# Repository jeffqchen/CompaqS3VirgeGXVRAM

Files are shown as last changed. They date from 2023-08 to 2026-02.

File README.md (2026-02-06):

# VRAM Expansion Board for Compaq S3 Virge GX & Matrox Mystique 220 Video Cards

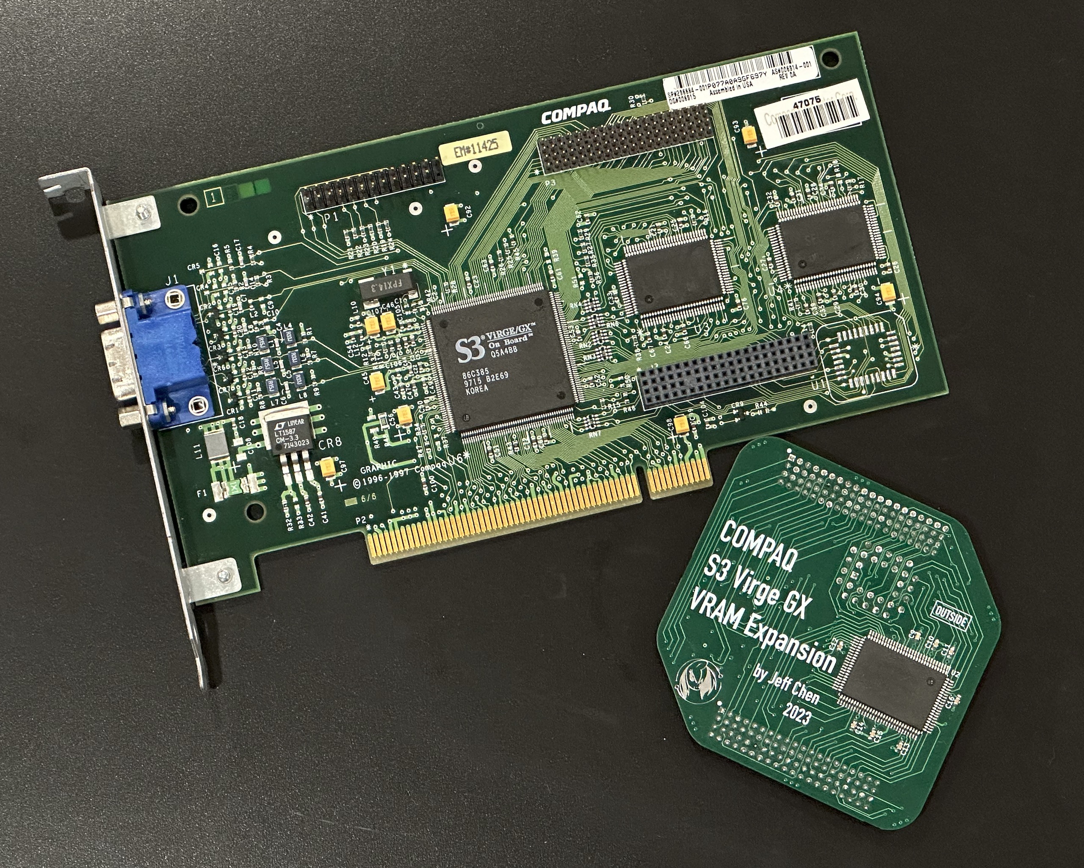
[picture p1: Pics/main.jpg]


The Compaq S3 Virge GX video card comes with 2MB of VRAM onboard, and a dual pin header interface for an add-on board to upgrade up to 4MB VRAM in total.

However, this add-on board is difficult to find at a reasonable price nowadays. Hence the need for this project.

Also, I've added additional support for a BIOS chip with a modern pinout scheme, in contrast to the weird one Compaq decided to use on their card. Just in case you are facing a corrupted BIOS situation, you can easily remove the stock one and install your own.

## Extra Compatibility

Later, I've noticed that this expansion board is also completely compatible with the Compaq Matrox Mystique 220, boosting the total VRAM to 4MB.



To learn all the findings I obtained during creating this board, as well as how to build the board, please visit the [Wiki](https://github.com/jeffqchen/CompaqS3VirgeGXVRAM/wiki) pages.

------------
Special Thanks

rain2xx - [Twitter](https://twitter.com/rain2xx)
- for extra photos of a 3rd party VRAM board
------------
Shield: [][cc-by-sa]

This work is licensed under a
[Creative Commons Attribution-ShareAlike 4.0 International License][cc-by-sa].

[][cc-by-sa]

[cc-by-sa]: http://creativecommons.org/licenses/by-sa/4.0/
[cc-by-sa-image]: https://licensebuttons.net/l/by-sa/4.0/88x31.png
[cc-by-sa-shield]: https://img.shields.io/badge/License-CC%20BY--SA%204.0-lightgrey.svg

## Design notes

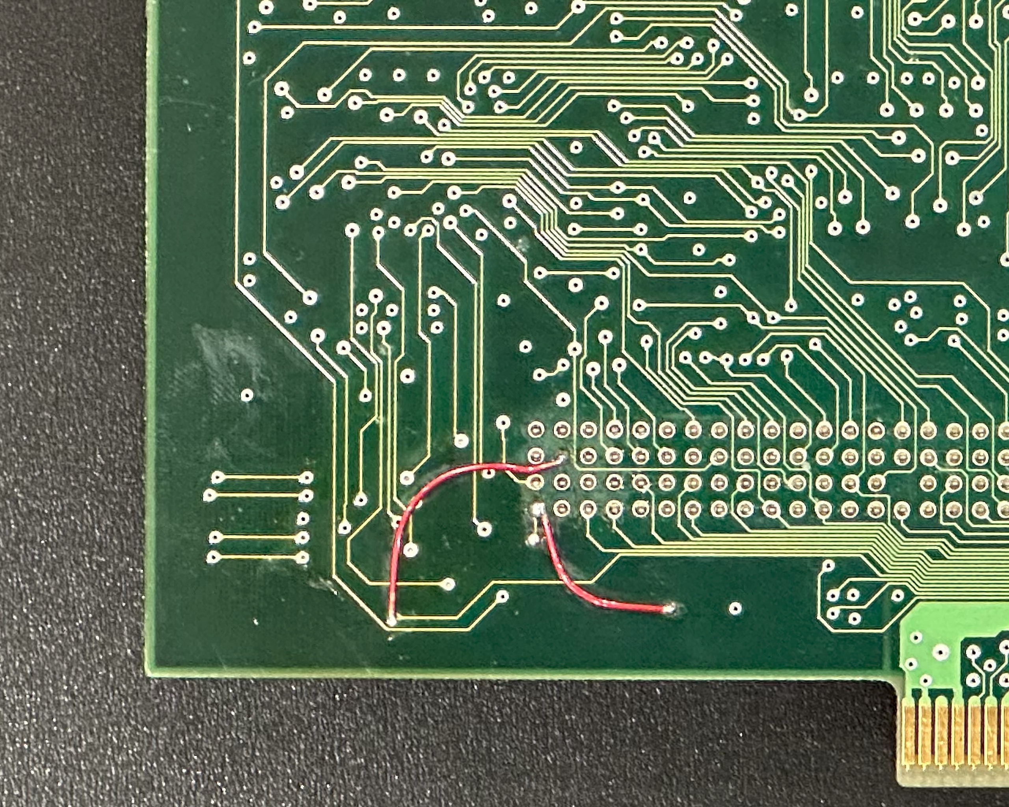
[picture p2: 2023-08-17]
Pics/bios_jumpers.jpg

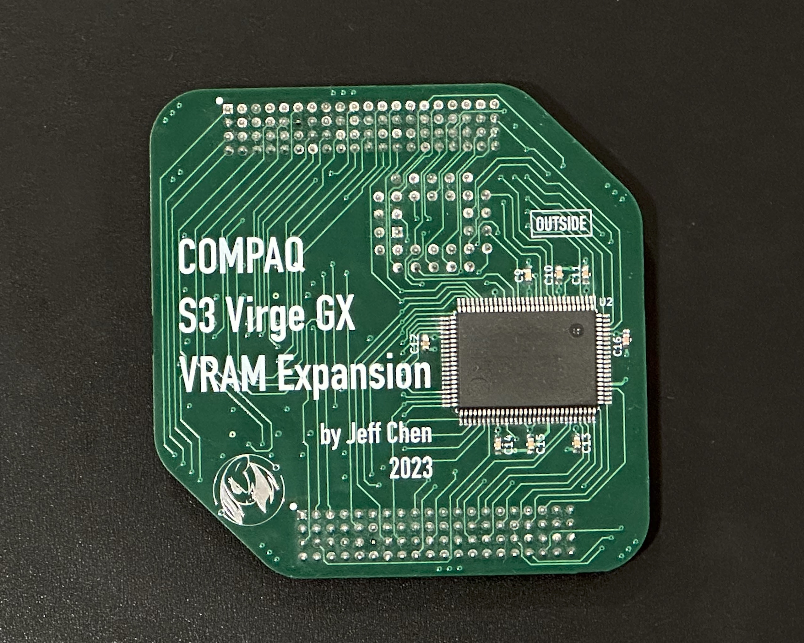
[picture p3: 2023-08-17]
Pics/board_top.jpg

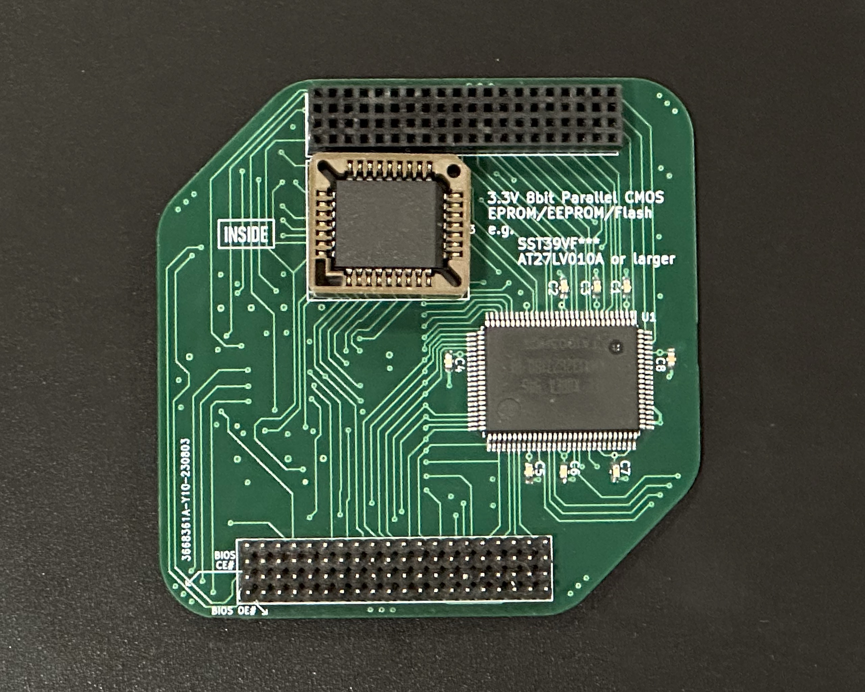
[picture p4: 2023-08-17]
Pics/board_bottom.jpg

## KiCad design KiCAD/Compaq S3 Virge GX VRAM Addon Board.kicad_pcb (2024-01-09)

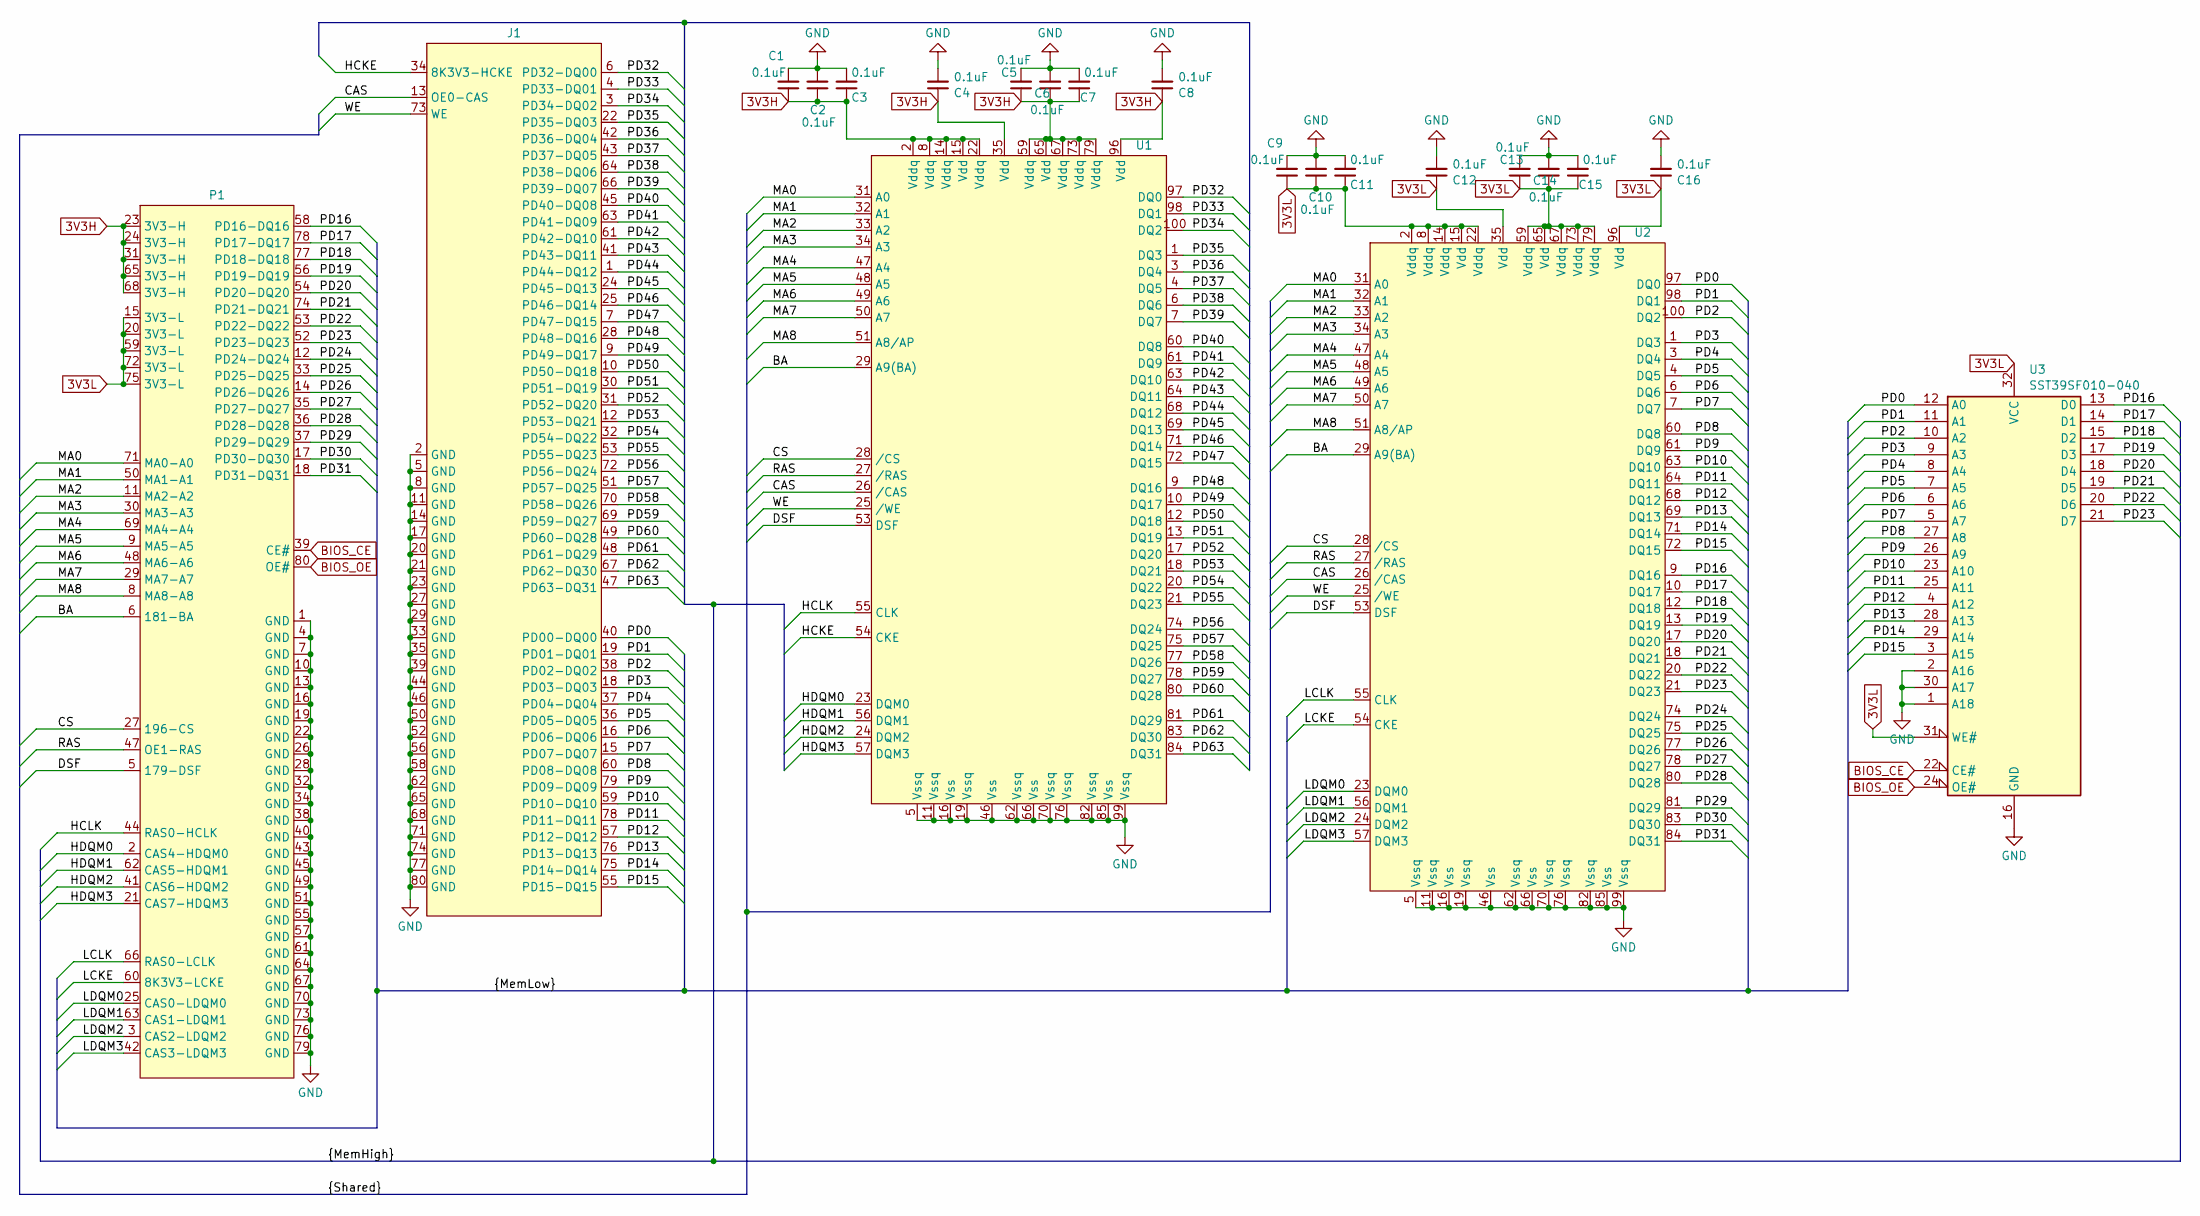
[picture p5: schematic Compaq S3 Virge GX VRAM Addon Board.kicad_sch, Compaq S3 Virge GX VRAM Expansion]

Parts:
C1, C2, C3, C4, C5, C6, C7, C8, C9, C10, C11, C12, C13, C14, C15, C16: 0.1uF; C_0603_1608Metric_Pad1.08x0.95mm_HandSolder
J1: Top Pin Header
P1: Bottom Pin Header
U1, U2: PQFP-100_14x20mm_P0.65mm
U3: SST39SF010-040; PLCC-32_THT-Socket

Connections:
3V3H: C1.1, C2.1, C3.1, C4.1, C5.1, C6.1, C7.1, C8.1, P1.23 (3V3-H), P1.24 (3V3-H), P1.31 (3V3-H), P1.65 (3V3-H), P1.68 (3V3-H), U1.2 (Vddq), U1.8 (Vddq), U1.14 (Vddq), U1.15 (Vdd), U1.22 (Vddq), U1.35 (Vdd), U1.59 (Vddq), U1.65 (Vdd), U1.67 (Vddq), U1.73 (Vddq), U1.79 (Vddq), U1.96 (Vdd)
3V3L: C9.1, C10.1, C11.1, C12.1, C13.1, C14.1, C15.1, C16.1, P1.15 (3V3-L), P1.20 (3V3-L), P1.59 (3V3-L), P1.72 (3V3-L), P1.75 (3V3-L), U2.2 (Vddq), U2.8 (Vddq), U2.14 (Vddq), U2.15 (Vdd), U2.22 (Vddq), U2.35 (Vdd), U2.59 (Vddq), U2.65 (Vdd), U2.67 (Vddq), U2.73 (Vddq), U2.79 (Vddq), U2.96 (Vdd), U3.31 (WE#), U3.32 (VCC)
/BA: P1.6 (181-BA), U1.29 (A9(BA)), U2.29 (A9(BA))
/CAS: J1.13 (OE0-CAS), U1.26 (/CAS), U2.26 (/CAS)
/CS: P1.27 (196-CS), U1.28 (/CS), U2.28 (/CS)
/DSF: P1.5 (179-DSF), U1.53 (DSF), U2.53 (DSF)
/HCKE: J1.34 (8K3V3-HCKE), U1.54 (CKE)
/HCLK: P1.44 (RAS0-HCLK), U1.55 (CLK)
/HDQM0: P1.2 (CAS4-HDQM0), U1.23 (DQM0)
/HDQM1: P1.62 (CAS5-HDQM1), U1.56 (DQM1)
/HDQM2: P1.41 (CAS6-HDQM2), U1.24 (DQM2)
/HDQM3: P1.21 (CAS7-HDQM3), U1.57 (DQM3)
/LCKE: P1.60 (8K3V3-LCKE), U2.54 (CKE)
/LCLK: P1.66 (RAS0-LCLK), U2.55 (CLK)
/LDQM0: P1.25 (CAS0-LDQM0), U2.23 (DQM0)
/LDQM1: P1.63 (CAS1-LDQM1), U2.56 (DQM1)
/LDQM2: P1.3 (CAS2-LDQM2), U2.24 (DQM2)
/LDQM3: P1.42 (CAS3-LDQM3), U2.57 (DQM3)
/MA0: P1.71 (MA0-A0), U1.31 (A0), U2.31 (A0)
/MA1: P1.50 (MA1-A1), U1.32 (A1), U2.32 (A1)
/MA2: P1.11 (MA2-A2), U1.33 (A2), U2.33 (A2)
/MA3: P1.30 (MA3-A3), U1.34 (A3), U2.34 (A3)
/MA4: P1.69 (MA4-A4), U1.47 (A4), U2.47 (A4)
/MA5: P1.9 (MA5-A5), U1.48 (A5), U2.48 (A5)
/MA6: P1.48 (MA6-A6), U1.49 (A6), U2.49 (A6)
/MA7: P1.29 (MA7-A7), U1.50 (A7), U2.50 (A7)
/MA8: P1.8 (MA8-A8), U1.51 (A8/AP), U2.51 (A8/AP)
/PD0: J1.40 (PD00-DQ00), U2.97 (DQ0), U3.12 (A0)
/PD1: J1.19 (PD01-DQ01), U2.98 (DQ1), U3.11 (A1)
/PD2: J1.38 (PD02-DQ02), U2.100 (DQ2), U3.10 (A2)
/PD3: J1.18 (PD03-DQ03), U2.1 (DQ3), U3.9 (A3)
/PD4: J1.37 (PD04-DQ04), U2.3 (DQ4), U3.8 (A4)
/PD5: J1.36 (PD05-DQ05), U2.4 (DQ5), U3.7 (A5)
/PD6: J1.16 (PD06-DQ06), U2.6 (DQ6), U3.6 (A6)
/PD7: J1.15 (PD07-DQ07), U2.7 (DQ7), U3.5 (A7)
/PD8: J1.60 (PD08-DQ08), U2.60 (DQ8), U3.27 (A8)
/PD9: J1.79 (PD09-DQ09), U2.61 (DQ9), U3.26 (A9)
/PD10: J1.59 (PD10-DQ10), U2.63 (DQ10), U3.23 (A10)
/PD11: J1.78 (PD11-DQ11), U2.64 (DQ11), U3.25 (A11)
/PD12: J1.57 (PD12-DQ12), U2.68 (DQ12), U3.4 (A12)
/PD13: J1.76 (PD13-DQ13), U2.69 (DQ13), U3.28 (A13)
/PD14: J1.75 (PD14-DQ14), U2.71 (DQ14), U3.29 (A14)
/PD15: J1.55 (PD15-DQ15), U2.72 (DQ15), U3.3 (A15)
/PD16: P1.58 (PD16-DQ16), U2.9 (DQ16), U3.13 (D0)
/PD17: P1.78 (PD17-DQ17), U2.10 (DQ17), U3.14 (D1)
/PD18: P1.77 (PD18-DQ18), U2.12 (DQ18), U3.15 (D2)
/PD19: P1.56 (PD19-DQ19), U2.13 (DQ19), U3.17 (D3)
/PD20: P1.54 (PD20-DQ20), U2.17 (DQ20), U3.18 (D4)
/PD21: P1.74 (PD21-DQ21), U2.18 (DQ21), U3.19 (D5)
/PD22: P1.53 (PD22-DQ22), U2.20 (DQ22), U3.20 (D6)
/PD23: P1.52 (PD23-DQ23), U2.21 (DQ23), U3.21 (D7)
/PD24: P1.12 (PD24-DQ24), U2.74 (DQ24)
/PD25: P1.33 (PD25-DQ25), U2.75 (DQ25)
/PD26: P1.14 (PD26-DQ26), U2.77 (DQ26)
/PD27: P1.35 (PD27-DQ27), U2.78 (DQ27)
/PD28: P1.36 (PD28-DQ28), U2.80 (DQ28)
/PD29: P1.37 (PD29-DQ29), U2.81 (DQ29)
/PD30: P1.17 (PD30-DQ30), U2.83 (DQ30)
/PD31: P1.18 (PD31-DQ31), U2.84 (DQ31)
/PD32: J1.6 (PD32-DQ00), U1.97 (DQ0)
/PD33: J1.4 (PD33-DQ01), U1.98 (DQ1)
/PD34: J1.3 (PD34-DQ02), U1.100 (DQ2)
/PD35: J1.22 (PD35-DQ03), U1.1 (DQ3)
/PD36: J1.42 (PD36-DQ04), U1.3 (DQ4)
/PD37: J1.43 (PD37-DQ05), U1.4 (DQ5)
/PD38: J1.64 (PD38-DQ06), U1.6 (DQ6)
/PD39: J1.66 (PD39-DQ07), U1.7 (DQ7)
/PD40: J1.45 (PD40-DQ08), U1.60 (DQ8)
/PD41: J1.63 (PD41-DQ09), U1.61 (DQ9)
/PD42: J1.61 (PD42-DQ10), U1.63 (DQ10)
/PD43: J1.41 (PD43-DQ11), U1.64 (DQ11)
/PD44: J1.1 (PD44-DQ12), U1.68 (DQ12)
/PD45: J1.24 (PD45-DQ13), U1.69 (DQ13)
/PD46: J1.25 (PD46-DQ14), U1.71 (DQ14)
/PD47: J1.7 (PD47-DQ15), U1.72 (DQ15)
/PD48: J1.28 (PD48-DQ16), U1.9 (DQ16)
/PD49: J1.9 (PD49-DQ17), U1.10 (DQ17)
/PD50: J1.10 (PD50-DQ18), U1.12 (DQ18)
/PD51: J1.30 (PD51-DQ19), U1.13 (DQ19)
/PD52: J1.31 (PD52-DQ20), U1.17 (DQ20)
/PD53: J1.12 (PD53-DQ21), U1.18 (DQ21)
/PD54: J1.32 (PD54-DQ22), U1.20 (DQ22)
/PD55: J1.53 (PD55-DQ23), U1.21 (DQ23)
/PD56: J1.72 (PD56-DQ24), U1.74 (DQ24)
/PD57: J1.51 (PD57-DQ25), U1.75 (DQ25)
/PD58: J1.70 (PD58-DQ26), U1.77 (DQ26)
/PD59: J1.69 (PD59-DQ27), U1.78 (DQ27)
/PD60: J1.49 (PD60-DQ28), U1.80 (DQ28)
/PD61: J1.48 (PD61-DQ29), U1.81 (DQ29)
/PD62: J1.67 (PD62-DQ30), U1.83 (DQ30)
/PD63: J1.47 (PD63-DQ31), U1.84 (DQ31)
/RAS: P1.47 (OE1-RAS), U1.27 (/RAS), U2.27 (/RAS)
/WE: J1.73 (WE), U1.25 (/WE), U2.25 (/WE)
BIOS_CE: P1.39 (CE#), U3.22 (CE#)
BIOS_OE: P1.80 (OE#), U3.24 (OE#)
GND: C1.2, C2.2, C3.2, C4.2, C5.2, C6.2, C7.2, C8.2, C9.2, C10.2, C11.2, C12.2, C13.2, C14.2, C15.2, C16.2, J1.2 (GND), J1.5 (GND), J1.8 (GND), J1.11 (GND), J1.14 (GND), J1.17 (GND), J1.20 (GND), J1.21 (GND), J1.23 (GND), J1.27 (GND), J1.29 (GND), J1.33 (GND), J1.35 (GND), J1.39 (GND), J1.44 (GND), J1.46 (GND), J1.50 (GND), J1.52 (GND), J1.56 (GND), J1.58 (GND), J1.62 (GND), J1.65 (GND), J1.68 (GND), J1.71 (GND), J1.74 (GND), J1.77 (GND), J1.80 (GND), P1.1 (GND), P1.4 (GND), P1.7 (GND), P1.10 (GND), P1.13 (GND), P1.16 (GND), P1.19 (GND), P1.22 (GND), P1.26 (GND), P1.28 (GND), P1.32 (GND), P1.34 (GND), P1.38 (GND), P1.40 (GND), P1.43 (GND), P1.45 (GND), P1.49 (GND), P1.51 (GND), P1.55 (GND), P1.57 (GND), P1.61 (GND), P1.64 (GND), P1.67 (GND), P1.70 (GND), P1.73 (GND), P1.76 (GND), P1.79 (GND), U1.5 (Vssq), U1.11 (Vssq), U1.16 (Vss), U1.19 (Vssq), U1.46 (Vss), U1.62 (Vssq), U1.66 (Vss), U1.70 (Vssq), U1.76 (Vssq), U1.82 (Vssq), U1.85 (Vss), U1.99 (Vssq), U2.5 (Vssq), U2.11 (Vssq), U2.16 (Vss), U2.19 (Vssq), U2.46 (Vss), U2.62 (Vssq), U2.66 (Vss), U2.70 (Vssq), U2.76 (Vssq), U2.82 (Vssq), U2.85 (Vss), U2.99 (Vssq), U3.1 (A18), U3.2 (A16), U3.16 (GND), U3.30 (A17)

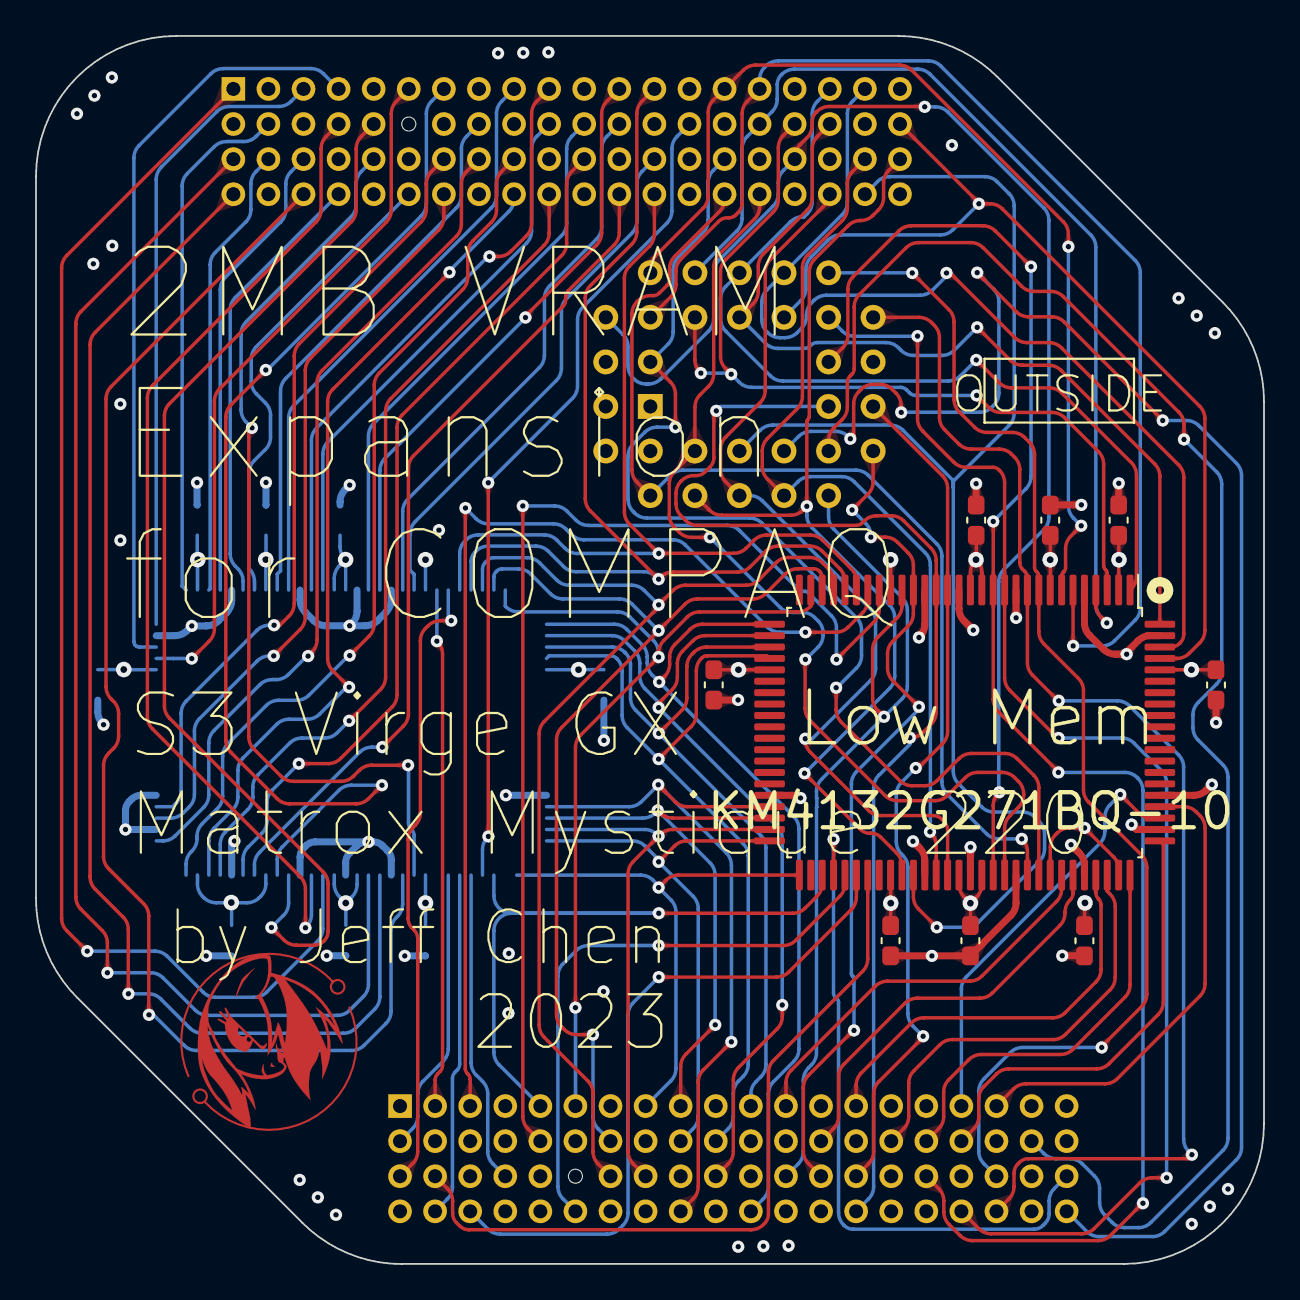
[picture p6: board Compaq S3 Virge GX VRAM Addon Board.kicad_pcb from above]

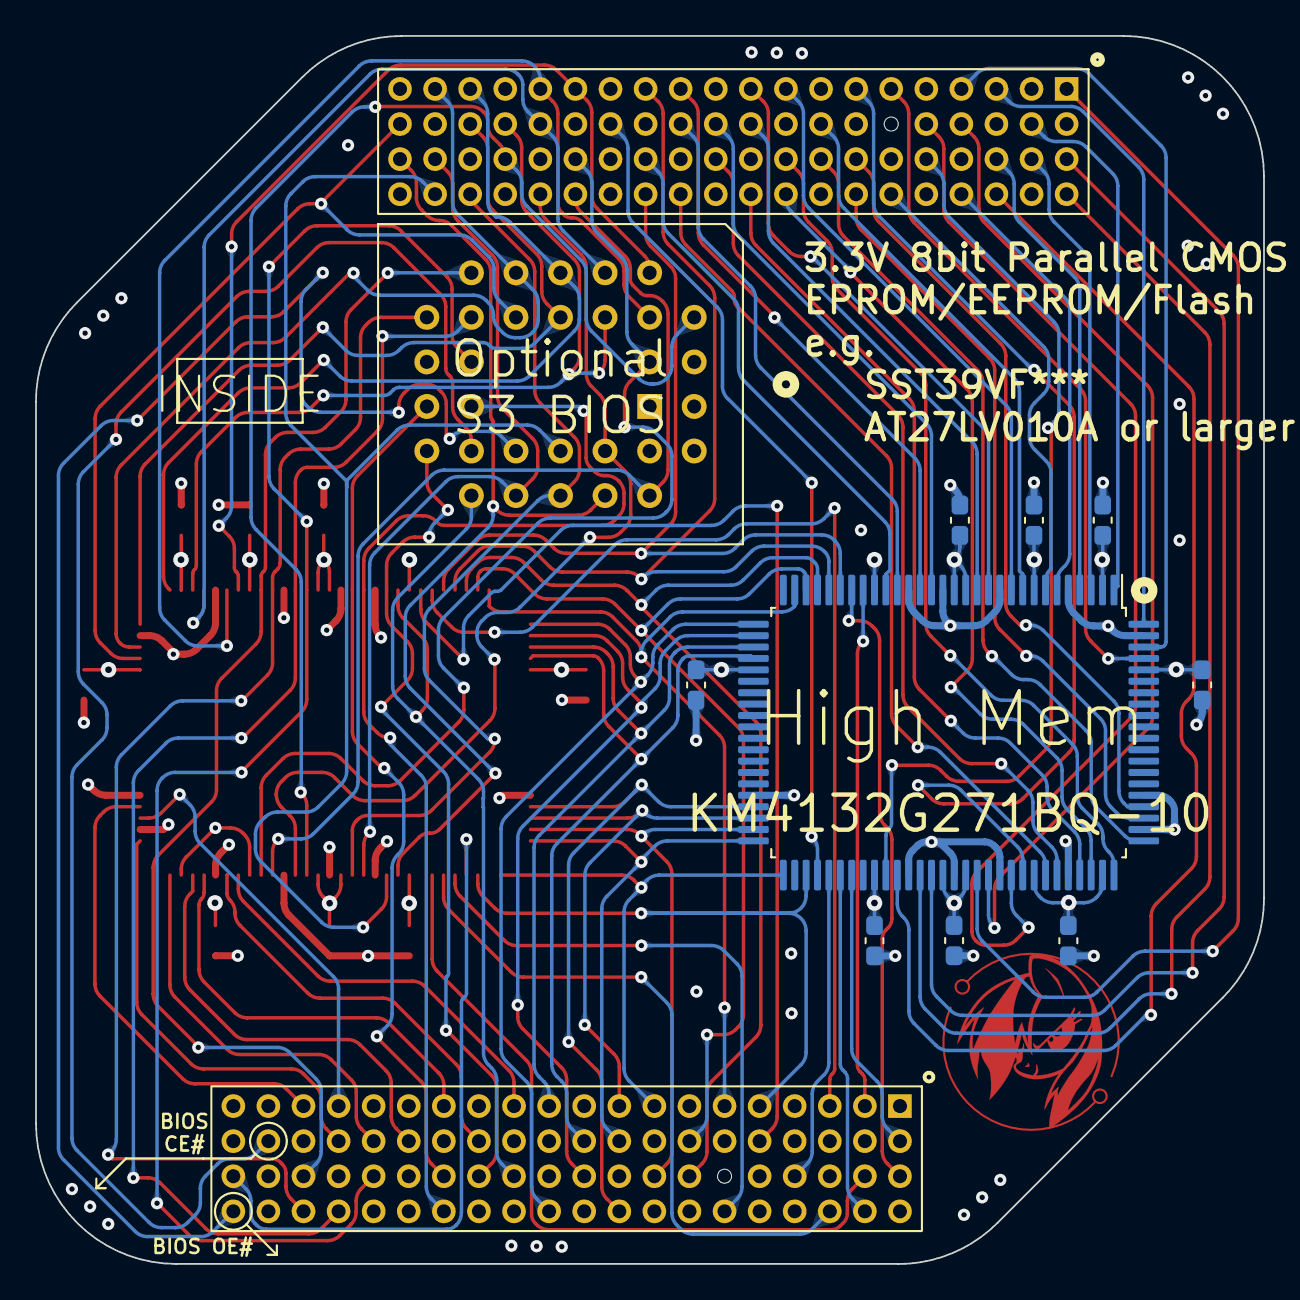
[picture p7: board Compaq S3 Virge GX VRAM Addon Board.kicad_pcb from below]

Board: 4 copper layers, 70.0 x 70.0 mm, 21 parts (10 on the bottom side), 96 nets.

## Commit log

2023-08-17 Add KiCAD files
    [Compaq S3 Virge GX VRAM Addon Board-B_Mask.gbr, Compaq S3 Virge GX VRAM Addon Board-B_Paste.gbr, Compaq S3 Virge GX VRAM Addon Board-B_Silkscreen.gbr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]
2024-01-09 Update PCB project
    Add Mystique 220 compatibility
    [Compaq S3 Virge GX VRAM Addon Board-B_Mask.gbr, Compaq S3 Virge GX VRAM Addon Board-B_Paste.gbr, Compaq S3 Virge GX VRAM Addon Board-B_Silkscreen.gbr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]

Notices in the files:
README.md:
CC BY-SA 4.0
